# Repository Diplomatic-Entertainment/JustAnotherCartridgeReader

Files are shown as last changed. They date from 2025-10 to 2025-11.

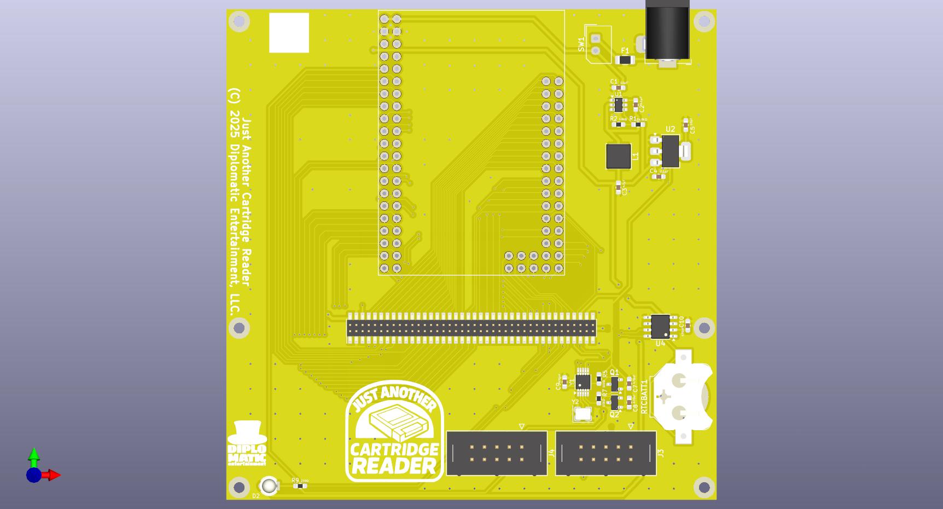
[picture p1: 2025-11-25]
Hardware/JACR_Front.jpg

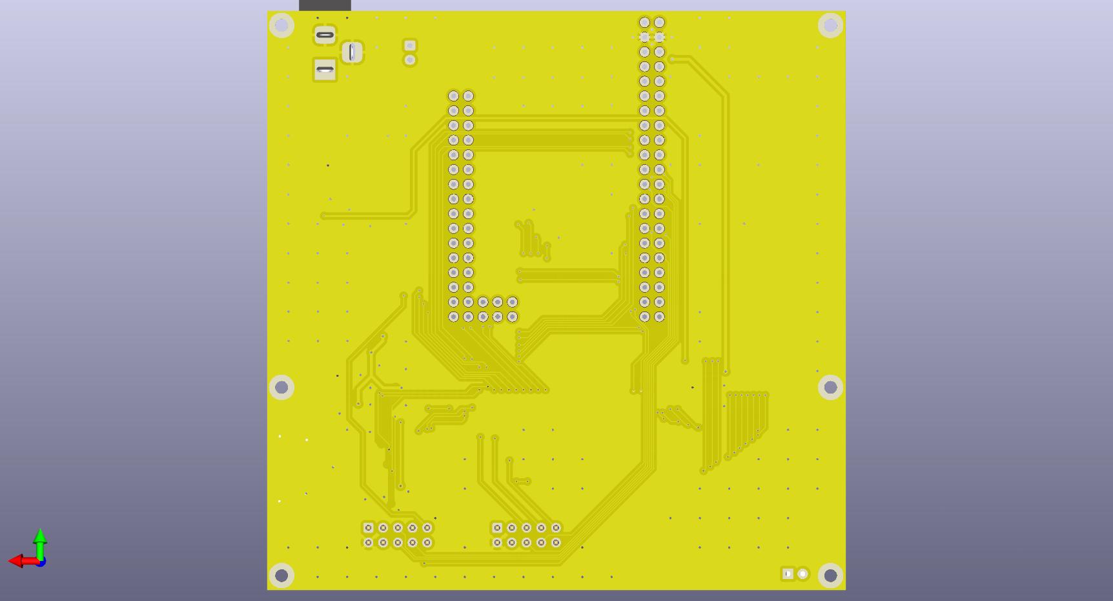
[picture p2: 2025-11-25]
Hardware/JACR_Back.jpg

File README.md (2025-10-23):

# JustAnotherCartridgeReader (JACR)
### An Open Source Cartridge Reader Derivative

JACR uses modified Firmware based on the OSCR Firmware - 
[Original OSCR Project](https://github.com/sanni/cartreader)

## What makes the JACR different from OSCR?
- JACR is designed with a dedicated power circuity allowing both 5V and 3.3V at the same time.  
- JACR uses a different design for adapaters, the pins back to the microcontroller remain the same but the pin pitch is altered and more power pins were added.  
- [JACR Adapters](https://github.com/Diplomatic-Entertainment/JACR-Adapters) are currently designed with logic level converters.   
- **JACR is not directly compatible with OSCR adapers and JACR Adapters are not directly compatible with the OSCR**

## What is the same as the OSCR?
- JACR uses the MEGA2560 microconroller  
- JACR has the RTC and ClockGEN built into the main board  
- Support for all the same Systems as the OSCR  
- JACR complies with Open Source Licensing with source code available for viewing and modifying  

### Open Source Licenses:
Software(everything in Firmware folder) = GPL v3  
Hardware(everything in hardware folder) = CC BY 4.0  
Complies with the original license of the OSCR where applicable

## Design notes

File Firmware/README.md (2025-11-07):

## This Arduino sketch is licensed under the GNU GENERAL PUBLIC LICENSE Version 3 (GPL v3)    

### This means that you are free to:    
- use, modify and distribute this software, even commercially    

### Under the following terms:    
- state changes   
- disclose source   
- same license   

### Limitations:
- Liability   
- Warranty   

More details: https://www.gnu.org/licenses/gpl-3.0.en.html    

## 

Every submodule has it's own setup_XX() function that configures the needed pins and a submenu that lets you choose what you want to do. 
The code directly addresses the pins via the DDR, PIN and PORT registers.   
Please also refer to the [pinout Open Office sheet](https://github.com/sanni/cartreader/blob/master/pinout.ods).    
```
void setup_N64_Controller() {  
  // Output a low signal  
  PORTH &= ~(1 << 4);  
  // Set Controller Data Pin(PH4) to Input  
  DDRH &= ~(1 << 4);  
}  
```

Would be the same as this in a more traditional Arduino sketch:  
```
int dataPin = 7;   

void setup(){    
  // Output a low signal   
  digitalWrite(dataPin, LOW);   
  // Set controller data pin to input  
  pinMode(dataPin, INPUT);  
}  
```
To preserve memory every string is saved into the flash of the Arduino, also called progmem. This is done by using the F() macro.   
```
println_Msg(F("Press Button."));  
```
Also all the menus are stored in progmem and are only recalled to sram when needed.  
```
// N64 controller menu items  
const char N64ContMenuItem1[] PROGMEM = "Test Controller";  
const char N64ContMenuItem2[] PROGMEM = "Read ControllerPak";  
const char N64ContMenuItem3[] PROGMEM = "Write ControllerPak";  
const char* const menuOptionsN64Controller[] PROGMEM = {N64ContMenuItem1, N64ContMenuItem2, N64ContMenuItem3, FSTRING_RESET};
```
In an effort to keep the codebase as portable as possible instead of using the functions supplied by the OLED library directly to print out text, auxiliary functions like `println_Msg` are being used. So if you want to change to another display library you don't need to change all the code but only the helper functions. 
```
void print_Msg(long unsigned int message) {
  if (ENABLE_OLED)
    display.print(message);
  if (ENABLE_SERIAL)
    Serial.print(message);
}
```

For more info please have a look at [this wiki article](https://github.com/sanni/cartreader/wiki/How-to-flash-the-Arduino).   

Needed libraries(already included in the portable Arduino IDE under Releases)   

SD lib: https://github.com/greiman/SdFat    
LCD lib: https://github.com/olikraus/U8g2_Arduino     
Neopixel lib: https://github.com/adafruit/Adafruit_NeoPixel    
Rotary Enc lib: https://github.com/mathertel/RotaryEncoder    
SI5351 lib: https://github.com/etherkit/Si5351Arduino        
RTC lib: https://github.com/adafruit/RTClib (needs BusIO lib: https://github.com/adafruit/Adafruit_BusIO)     
Frequency Counter lib: https://github.com/PaulStoffregen/FreqCount    

### JACR Modifications 
- Renaming directory from cart_reader to firmware forced cart_reader.ino to be renamed firmware.ino
  - Added JACR as hardware refernce where HW5 is also defined
  - Made reference back to OSCR in About
  - Removed 1K Resistor Check in Self Test
  - Removed reset on failure in Self Test
- Modified config.ino
  - JACR is currently based on the HW5 revision
  - Noted to not change HW selection
  - Noted to not enable VSELECT
  - Clock Generator enabled
  - RTC enabled
  - Noted to not enable 3V3FIX (not needed on JACR)
  - Noted to not enable Stability Fix (not need on JACR)
  - Noted to not enable the updated (untested, unlikely to work with intended results) 
  - Enabled SNES Core/CLOCKGEN by default
- Modified oscr.cpp
  - Added JACR suffix to FSTRING_VERSION
  - Changed FSTRING_OSCR from OSCR to JACR
  - Comment out setClockScale VOLTS and CLKSCALE (unused)

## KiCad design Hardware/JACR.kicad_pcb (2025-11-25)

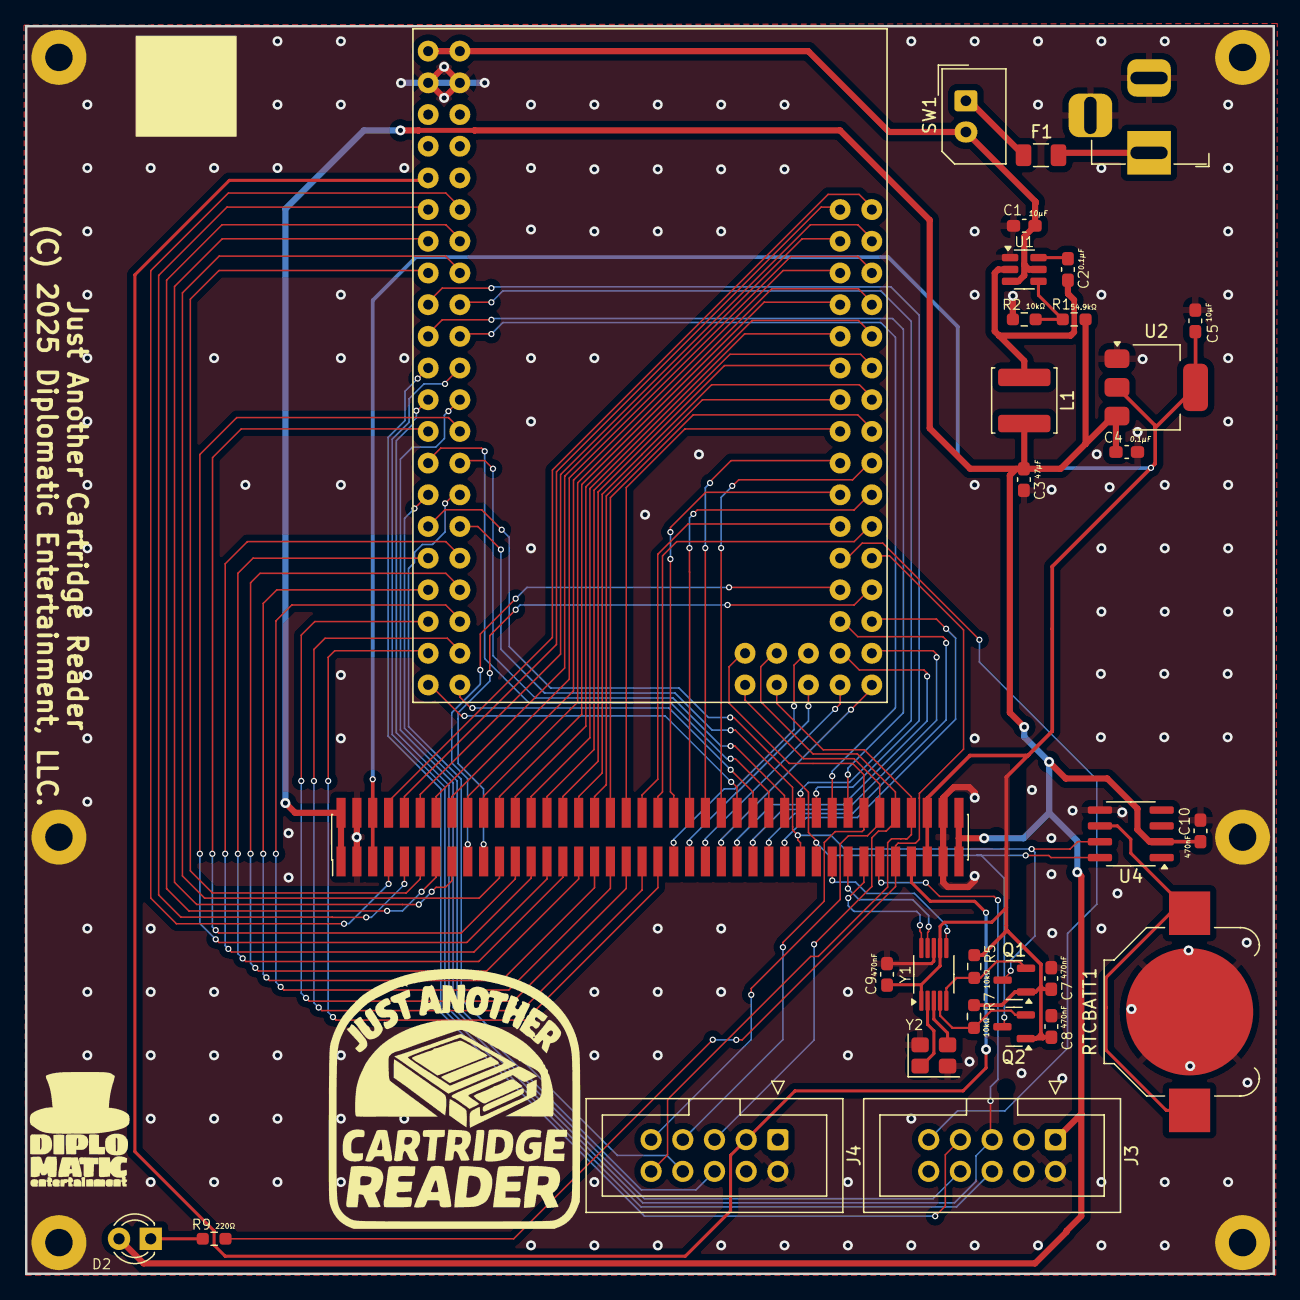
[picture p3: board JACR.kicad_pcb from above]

Board: 2 copper layers, 100.0 x 100.0 mm, 38 parts (0 on the bottom side), 89 nets.

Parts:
BAR**: 2D Barcode 8mm
C1, C5: 10µF; C_0603_1608Metric_Pad1.08x0.95mm_HandSolder
C2, C4: 0.1µF; C_0603_1608Metric_Pad1.08x0.95mm_HandSolder
C3: 47µF; C_0603_1608Metric_Pad1.08x0.95mm_HandSolder
C7, C8, C9, C10: 470nF; C_0603_1608Metric_Pad1.08x0.95mm_HandSolder
D2: LED; LED_D3.0mm_Clear
F1: 1A; Fuse_1206_3216Metric
J1: Barrel_Jack_Switch; BarrelJack_Horizontal
J2: JACR CARTRIDGE SLOT; PinHeader_2x40_P1.27mm_Vertical_SMD
J3: EXP1; IDC-Header_2x05_P2.54mm_Vertical
J4: EXP2; IDC-Header_2x05_P2.54mm_Vertical
L1: 4.7µH; L_APV_ANR5040
M1, M2, M3, M4, M4#2, M4#3: MountingHole_2.2mm_M2_Pad
Q1, Q2: BSS138; SOT-23
R1: 54.9kΩ; R_0603_1608Metric_Pad0.98x0.95mm_HandSolder
R2, R5, R7: 10kΩ; R_0603_1608Metric_Pad0.98x0.95mm_HandSolder
R9: 220Ω; R_0603_1608Metric_Pad0.98x0.95mm_HandSolder
RTCBATT1: Battery_Cell; BatteryHolder_Keystone_3000_1x12mm
SW1: SW_SPST; Molex_SPOX_5267-02A_1x02_P2.50mm_Vertical
U1: TPS562200; SOT-23-6
U2: LD1117S33; SOT-223-3_TabPin2
U4: DS3231MZ; SOIC-8_3.9x4.9mm_P1.27mm
U5: MEGA PRO EMBEDED 2560; MODULE_MEGA_PRO_EMBED_CH340G___ATMEGA2560_SMD
Y1: Si5351A-B-GT; MSOP-10_3x3mm_P0.5mm
Y2: 25Mhz; Crystal_SMD_3225-4Pin_3.2x2.5mm

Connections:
+3V3: C5.1, C7.1, C8.1, C9.1, J2.5 (+3V3), J2.6 (+3V3), J2.75 (+3V3), J2.76 (+3V3), Q1.1 (G), Q2.1 (G), R5.1, R7.1, U2.2 (VO), Y1.1 (VDD), Y1.7 (VDDO)
+5V: C3.1, C4.1, C10.1, D2.2 (A), J2.1 (+5V), J2.2 (+5V), J2.79 (+5V), J2.80 (+5V), J3.1, L1.2, R1.1, U2.3 (VI), U4.2 (VCC)
/SCL: Q2.2 (S), R7.2, Y1.4 (SCL)
/SDA: Q1.2 (S), R5.2, Y1.5 (SDA)
/VBAT: RTCBATT1.1 (+), U4.6 (VBAT)
A0: J2.8 (A0), U5.A0
A1: J2.10 (A1), U5.A1
A2: J2.12 (A2), U5.A2
A3: J2.14 (A3), U5.A3
A4: J2.16 (A4), U5.A4
A5: J2.18 (A5), U5.A5
A6: J2.20 (A6), U5.A6
A7: J2.22 (A7), U5.A7
A8: J2.24 (A8), U5.A8
A9: J2.26 (A9), U5.A9
A10: J2.28 (A10), U5.A10
A11: J2.30 (A11), U5.A11
A12: J2.32 (A12), U5.A12
A13: J2.34 (A13), U5.A13
A14: J2.36 (A14), U5.A14
A15: J2.38 (A15), U5.A15
CLK0: J2.67 (CLK0), Y1.10 (CLK0)
CLK1: J2.65 (CLK1), Y1.9 (CLK1)
CLK2: J2.63 (CLK2), Y1.6 (CLK2)
D0: J2.7 (D0), U5.RX_D0
D1: J2.9 (D1), U5.TX_D1
D2: J2.13 (D2), U5.D2
D3: J2.15 (D3), U5.D3
D4: J2.21 (D4), U5.D4
D5: J2.11 (D5), U5.D5
D6: J2.60 (D6), U5.D6
D7: J2.62 (D7), U5.D7
D8: J2.64 (D8), U5.D8
D9: J2.66 (D9), U5.D9
D10: J3.6, U5.D10
D11: J3.7, U5.D11
D12: J3.8, U5.D12
D13: J2.69 (D13), J3.5, U5.D13
D14: J2.25 (D14), U5.D14
D15: J2.23 (D15), U5.D15
D16: J2.58 (D16), U5.D16
D17: J2.56 (D17), U5.D17
D18: J4.8, U5.D18
D19: J4.6, U5.D19
D20: J2.59 (D20), Q1.3 (D), U4.7 (SDA), U5.D20
D21: J2.61 (D21), Q2.3 (D), U4.8 (SCL), U5.D21
D22: J2.27 (D22), U5.D22
D23: J2.29 (D23), U5.D23
D24: J2.31 (D24), U5.D24
D25: J2.33 (D25), U5.D25
D26: J2.35 (D26), U5.D26
D27: J2.37 (D27), U5.D27
D28: J2.39 (D28), U5.D28
D29: J2.41 (D29), U5.D29
D30: J2.54 (D30), U5.D30
D31: J2.52 (D31), U5.D31
D32: J2.50 (D32), U5.D32
D33: J2.48 (D33), U5.D33
D34: J2.46 (D34), U5.D34
D35: J2.44 (D35), U5.D35
D36: J2.42 (D36), U5.D36
D37: J2.40 (D37), U5.D37
D38: J2.71 (D38), R9.2, U5.D38
D39: J3.9, U5.D39
D40: J2.19 (D40), U5.D40
D41: J2.17 (D41), U5.D41
D42: J2.57 (D42), U5.D42
D43: J2.55 (D43), U5.D43
D44: J2.53 (D44), U5.D44
D45: J2.51 (D45), U5.D45
D46: J2.49 (D46), U5.D46
D47: J2.47 (D47), U5.D47
D48: J2.45 (D48), U5.D48
D49: J2.43 (D49), U5.D49
D50: J2.74 (D50), J4.10, U5.D50
D51: J2.72 (D51), J4.5, U5.D51
D52: J2.70 (D52), J4.9, U5.D52
D53: J2.68 (D53), J4.7, U5.D53
GND: C1.2, C3.2, C4.2, C5.2, C7.2, C8.2, C9.2, C10.2, J1.2, J1.3, J2.3 (GND), J2.4 (GND), J2.77 (GND), J2.78 (GND), J3.2, J4.2, M1.1, M2.1, M3.1, M4.1, M4#2.1, M4#3.1, R2.2, RTCBATT1.2 (-), U1.1 (GND), U2.1 (GND), U4.5 (GND), U5.GND_1, U5.GND_2, Y1.8 (GND), Y2.2, Y2.4
unnamed: D2.1 (K), R9.1
unnamed: F1.1, J1.1
unnamed: F1.2, SW1.1 (A)
unnamed: C2.1, L1.1, U1.2 (SW)
unnamed: C2.2, U1.6 (VBST)
unnamed: R1.2, R2.1, U1.4 (VFB)
unnamed: Y1.2 (XA), Y2.1
unnamed: Y1.3 (XB), Y2.3
RST: J2.73 (RESET), J4.3, U5.RST
VCC: C1.1, SW1.2 (B), U1.3 (VIN), U1.5 (EN), U5.VIN_1, U5.VIN_2

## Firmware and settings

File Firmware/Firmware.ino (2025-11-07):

/**********************************************************************************
                    Cartridge Reader for Arduino Mega2560

   This project represents a community-driven effort to provide
   an easy to build and easy to modify cartridge dumper.

   SD lib: https://github.com/greiman/SdFat
   LCD lib: https://github.com/olikraus/u8g2
   Neopixel lib: https://github.com/adafruit/Adafruit_NeoPixel
   Rotary Enc lib: https://github.com/mathertel/RotaryEncoder
   SI5351 lib: https://github.com/etherkit/Si5351Arduino
   RTC lib: https://github.com/adafruit/RTClib
   Frequency lib: https://github.com/PaulStoffregen/FreqCount

   Thanks to:
   MichlK - ROM Reader for Super Nintendo
   Jeff Saltzman - 4-Way Button
   Wayne and Layne - Video Game Shield menu
   skaman - Cart ROM READER SNES ENHANCED, Famicom Cart Dumper, 2600, 5200, 7800, ARC, ATARI8, BALLY, C64, COLV, FAIRCHILD,
   INTV, LEAP, LJ, LJPRO, MSX, ODY2, PCW, POKEMINI, PV1000, PYUUTA, RCA, TI99, TRS80, VBOY, VECTREX, WSV, VIC20, VSMILE modules
   Tamanegi_taro - PCE and Satellaview modules
   splash5 - GBSmart, Wonderswan, NGP and Super A'can modules
   partlyhuman - Casio Loopy & Atari Lynx module
   hkz & themanbehindthecurtain - N64 flashram commands
   Andrew Brown & Peter Den Hartog - N64 controller protocol
   libdragon - N64 controller checksum functions
   Angus Gratton - CRC32
   Snes9x - SuperFX sram fix
   insidegadgets - GBCartRead
   RobinTheHood - GameboyAdvanceRomDumper
   Gens-gs - Megadrive checksum
   fceux - iNes header
   PsyK0p4T - Sufami Turbo module
   LuigiBlood - SNES Game Processor RAM Cassette module
   herzmx - CPS3 module

   And a special Thank You to all coders and contributors on Github and the Arduino forum:
   Ancyker, Andy-miles, BacteriaMage, Borti4938, Breyell, ButThouMust, CaitSith2, Chomemel, Dakkaron, Ducky92, Fakkuyuu, Gemarcano,
   Hxlnt, InvalidInterrupt, Jiyunomegami, Joshman196, Karimhadjsalem, Kreeblah, Lesserkuma, LuigiBlood, Majorpbx, Mattiacci, Modman,
   Niklasweber, Nsx0r, Partlyhuman, Philenotfound, Pickle, Plaidpants, PsychoFox11, PsyK0p4T, Qufb, RWeick, Ramapcsx2, Sakman55,
   Scrap-a, Sdhizumi, Smesgr9000, Splash5, Tombo89, Uzlopak, Vogelfreiheit, Vpelletier, Wfmarques

   And to nocash for figuring out the secrets of the SFC Nintendo Power cartridge.

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
**********************************************************************************/

#include "OSCR.h"

/******************************************
   Libraries
 *****************************************/

// SD Card
SdFs sd;
FsFile myFile;
#ifdef ENABLE_GLOBAL_LOG
FsFile myLog;
bool dont_log = false;
#endif

// AVR Eeprom
#include <EEPROM.h>
// forward declarations for "T" (for non Arduino IDE)
template<class T> int EEPROM_writeAnything(int ee, const T& value);
template<class T> int EEPROM_readAnything(int ee, T& value);

// Graphic SPI LCD
#ifdef ENABLE_LCD
#include <U8g2lib.h>
U8G2_ST7567_OS12864_F_4W_HW_SPI display(U8G2_R2, /* cs=*/12, /* dc=*/11, /* reset=*/10);
#endif

// Rotary Encoder
#ifdef ENABLE_ROTARY
#include <RotaryEncoder.h>
#define PIN_IN1 18
#define PIN_IN2 19
#ifdef rotate_counter_clockwise
RotaryEncoder encoder(PIN_IN2, PIN_IN1, RotaryEncoder::LatchMode::FOUR3);
#else
RotaryEncoder encoder(PIN_IN1, PIN_IN2, RotaryEncoder::LatchMode::FOUR3);
#endif
int rotaryPos = 0;
#endif

// Choose RGB LED type
#ifdef ENABLE_NEOPIXEL
// Neopixel
#include <Adafruit_NeoPixel.h>
Adafruit_NeoPixel pixels(3, 13, NEO_GRB + NEO_KHZ800);
#endif

typedef enum COLOR_T {
  blue_color,
  red_color,
  purple_color,
  green_color,
  turquoise_color,
  yellow_color,
  white_color,
  black_color,
} color_t;

// Graphic I2C OLED
#ifdef ENABLE_OLED
#include <U8g2lib.h>
U8G2_SSD1306_128X64_NONAME_F_HW_I2C display(U8G2_R0, /* reset=*/U8X8_PIN_NONE);
#endif

// Etherkit Clock Generator
#include <si5351.h>
Si5351 clockgen;
bool i2c_found;

// RTC Library
#ifdef ENABLE_RTC
#define _RTC_H
#include "RTClib.h"
#endif

// Clockgen Calibration
#ifdef OPTION_CLOCKGEN_CALIBRATION
#include "FreqCount.h"
#endif

void _print_FatalError(void) __attribute__((noreturn));
void print_FatalError(const __FlashStringHelper* errorMessage) __attribute__((noreturn));
void print_FatalError(byte errorMessage) __attribute__((noreturn));

/******************************************
  End of inclusions and forward declarations
 *****************************************/

template<class T> int EEPROM_writeAnything(int ee, const T& value) {
  const byte* p = (const byte*)(const void*)&value;
  unsigned int i;
  for (i = 0; i < sizeof(value); i++)
    EEPROM.write(ee++, *p++);
  return i;
}

template<class T> int EEPROM_readAnything(int ee, T& value) {
  byte* p = (byte*)(void*)&value;
  unsigned int i;
  for (i = 0; i < sizeof(value); i++)
    *p++ = EEPROM.read(ee++);
  return i;
}

/******************************************
  Common Strings
 *****************************************/
#define press_button_STR 0
#define sd_error_STR 1
#define reset_STR 2
#define did_not_verify_STR 3
#define _bytes_STR 4
#define error_STR 5
#define create_file_STR 6
#define open_file_STR 7
#define file_too_big_STR 8
#define done_STR 9
#define saving_to_STR 10
#define verifying_STR 11
#define flashing_file_STR 12
#define press_to_change_STR 13
#define right_to_select_STR 14
#define rotate_to_change_STR 15
#define press_to_select_STR 16

// This array holds the most often used strings
constexpr char string_press_button0[] PROGMEM = "Press Button...";
constexpr char string_sd_error1[] PROGMEM = "SD Error";
constexpr char string_did_not_verify3[] PROGMEM = "did not verify";
constexpr char string_bytes4[] PROGMEM = " bytes ";
constexpr char string_error5[] PROGMEM = "Error: ";
constexpr char string_create_file6[] PROGMEM = "Can't create file";
constexpr char string_open_file7[] PROGMEM = "Can't open file";
constexpr char string_file_too_big8[] PROGMEM = "File too big";
constexpr char string_done9[] PROGMEM = "Done";
constexpr char string_saving_to10[] PROGMEM = "Saving to ";
constexpr char string_verifying11[] PROGMEM = "Verifying...";
constexpr char string_flashing_file12[] PROGMEM = "Flashing file ";
constexpr char string_press_to_change13[] PROGMEM = "Press left to Change";
constexpr char string_right_to_select14[] PROGMEM = "and right to Select";
constexpr char string_rotate_to_change15[] PROGMEM = "Rotate to Change";
constexpr char string_press_to_select16[] PROGMEM = "Press to Select";

static constexpr const char* const string_table[] PROGMEM = {
  string_press_button0, string_sd_error1, FSTRING_RESET,
  string_did_not_verify3, string_bytes4, string_error5, string_create_file6,
  string_open_file7, string_file_too_big8, string_done9, string_saving_to10,
  string_verifying11, string_flashing_file12, string_press_to_change13,
  string_right_to_select14, string_rotate_to_change15, string_press_to_select16
};

void print_STR(byte string_number, boolean newline) {
  if (newline)
    println_Msg(FS(pgm_read_word(string_table + string_number)));
  else
    print_Msg(FS(pgm_read_word(string_table + string_number)));
}

/******************************************
  Defines
 *****************************************/

// optimization-safe nop delay
#define NOP __asm__ __volatile__("nop\n\t")

// Button timing
#define debounce 20        // ms debounce period to prevent flickering when pressing or releasing the button
#define DCgap 250          // max ms between clicks for a double click event
#define holdTime 2000      // ms hold period: how long to wait for press+hold event
#define longHoldTime 5000  // ms long hold period: how long to wait for press+hold event

/******************************************
   Variables
 *****************************************/
#ifdef ENABLE_ROTARY
// Button debounce
boolean buttonState = HIGH;          // the current reading from the input pin
boolean lastButtonState = HIGH;      // the previous reading from the input pin
unsigned long lastDebounceTime = 0;  // the last time the output pin was toggled
unsigned long debounceDelay = 50;    // the debounce time; increase if the output flickers
#endif

#ifdef ENABLE_OLED
// Button 1
boolean buttonVal1 = HIGH;           // value read from button
boolean buttonLast1 = HIGH;          // buffered value of the button's previous state
boolean DCwaiting1 = false;          // whether we're waiting for a double click (down)
boolean DConUp1 = false;             // whether to register a double click on next release, or whether to wait and click
boolean singleOK1 = true;            // whether it's OK to do a single click
long downTime1 = -1;                 // time the button was pressed down
long upTime1 = -1;                   // time the button was released
boolean ignoreUp1 = false;           // whether to ignore the button release because the click+hold was triggered
boolean waitForUp1 = false;          // when held, whether to wait for the up event
boolean holdEventPast1 = false;      // whether or not the hold event happened already
boolean longholdEventPast1 = false;  // whether or not the long hold event happened already
// Button 2
boolean buttonVal2 = HIGH;           // value read from button
boolean buttonLast2 = HIGH;          // buffered value of the button's previous state
boolean DCwaiting2 = false;          // whether we're waiting for a double click (down)
boolean DConUp2 = false;             // whether to register a double click on next release, or whether to wait and click
boolean singleOK2 = true;            // whether it's OK to do a single click
long downTime2 = -1;                 // time the button was pressed down
long upTime2 = -1;                   // time the button was released
boolean ignoreUp2 = false;           // whether to ignore the button release because the click+hold was triggered
boolean waitForUp2 = false;          // when held, whether to wait for the up event
boolean holdEventPast2 = false;      // whether or not the hold event happened already
boolean longholdEventPast2 = false;  // whether or not the long hold event happened already
#endif

// Variables for the menu
int choice = 0;
// Temporary array that holds the menu option read out of progmem
char menuOptions[7][20];
boolean ignoreError = 0;

// File browser
#define FILENAME_LENGTH 100
#define FILEPATH_LENGTH 132
#define FILEOPTS_LENGTH 20

char fileName[FILENAME_LENGTH];
char filePath[FILEPATH_LENGTH];
byte currPage;
byte lastPage;
byte numPages;
boolean root = 0;
boolean filebrowse = 0;

// Common
// 21 chars for ROM name, one char for termination
char romName[22];
unsigned long sramSize = 0;
int romType = 0;
byte saveType;
word romSize = 0;
word numBanks = 128;
char checksumStr[9];
bool errorLvl = 0;
byte romVersion = 0;
char cartID[5];
unsigned long cartSize;
unsigned int flashid;
char flashid_str[5];
char vendorID[5];
unsigned long fileSize;
unsigned long sramBase;
unsigned long flashBanks;
bool flashX16Mode;
bool flashSwitchLastBits;

// Variable to count errors
unsigned long writeErrors;

// Operation mode
CORES mode = CORE_MAX;

//remember folder number to create a new folder for every game
int foldern;
// 4 chars for console type, 4 chars for SAVE/ROM, 21 chars for ROM name, 4 chars for folder number, 3 chars for slashes, one char for termination, one char savety
char folder[38];

// Array that holds the data
byte sdBuffer[512];

// soft reset Arduino: jumps to 0
// using the watchdog timer would be more elegant but some Mega2560 bootloaders are buggy with it
void (*resetArduino)(void) __attribute__((noreturn)) = 0;

// Progressbar
void draw_progressbar(uint32_t processedsize, uint32_t totalsize);

// used by MD and NES modules
byte eepbit[8];
byte eeptemp;

// Array to hold iNES header
byte iNES_HEADER[16];
//ID 0-3
//ROM_size 4
//VROM_size 5
//ROM_type 6
//ROM_type2 7
//ROM_type3 8
//Upper_ROM_VROM_size 9
//RAM_size 10
//VRAM_size 11
//TV_system 12
//VS_hardware 13
//reserved 14, 15

//******************************************
// CRC32
//******************************************
// CRC32 lookup table // 256 entries
constexpr uint32_t crc_32_tab[] PROGMEM = { /* CRC polynomial 0xedb88320 */
  0x00000000, 0x77073096, 0xee0e612c, 0x990951ba, 0x076dc419, 0x706af48f,
  0xe963a535, 0x9e6495a3, 0x0edb8832, 0x79dcb8a4, 0xe0d5e91e, 0x97d2d988,
  0x09b64c2b, 0x7eb17cbd, 0xe7b82d07, 0x90bf1d91, 0x1db71064, 0x6ab020f2,
  0xf3b97148, 0x84be41de, 0x1adad47d, 0x6ddde4eb, 0xf4d4b551, 0x83d385c7,
  0x136c9856, 0x646ba8c0, 0xfd62f97a, 0x8a65c9ec, 0x14015c4f, 0x63066cd9,
  0xfa0f3d63, 0x8d080df5, 0x3b6e20c8, 0x4c69105e, 0xd56041e4, 0xa2677172,
  0x3c03e4d1, 0x4b04d447, 0xd20d85fd, 0xa50ab56b, 0x35b5a8fa, 0x42b2986c,
  0xdbbbc9d6, 0xacbcf940, 0x32d86ce3, 0x45df5c75, 0xdcd60dcf, 0xabd13d59,
  0x26d930ac, 0x51de003a, 0xc8d75180, 0xbfd06116, 0x21b4f4b5, 0x56b3c423,
  0xcfba9599, 0xb8bda50f, 0x2802b89e, 0x5f058808, 0xc60cd9b2, 0xb10be924,
  0x2f6f7c87, 0x58684c11, 0xc1611dab, 0xb6662d3d, 0x76dc4190, 0x01db7106,
  0x98d220bc, 0xefd5102a, 0x71b18589, 0x06b6b51f, 0x9fbfe4a5, 0xe8b8d433,
  0x7807c9a2, 0x0f00f934, 0x9609a88e, 0xe10e9818, 0x7f6a0dbb, 0x086d3d2d,
  0x91646c97, 0xe6635c01, 0x6b6b51f4, 0x1c6c6162, 0x856530d8, 0xf262004e,
  0x6c0695ed, 0x1b01a57b, 0x8208f4c1, 0xf50fc457, 0x65b0d9c6, 0x12b7e950,
  0x8bbeb8ea, 0xfcb9887c, 0x62dd1ddf, 0x15da2d49, 0x8cd37cf3, 0xfbd44c65,
  0x4db26158, 0x3ab551ce, 0xa3bc0074, 0xd4bb30e2, 0x4adfa541, 0x3dd895d7,
  0xa4d1c46d, 0xd3d6f4fb, 0x4369e96a, 0x346ed9fc, 0xad678846, 0xda60b8d0,
  0x44042d73, 0x33031de5, 0xaa0a4c5f, 0xdd0d7cc9, 0x5005713c, 0x270241aa,
  0xbe0b1010, 0xc90c2086, 0x5768b525, 0x206f85b3, 0xb966d409, 0xce61e49f,
  0x5edef90e, 0x29d9c998, 0xb0d09822, 0xc7d7a8b4, 0x59b33d17, 0x2eb40d81,
  0xb7bd5c3b, 0xc0ba6cad, 0xedb88320, 0x9abfb3b6, 0x03b6e20c, 0x74b1d29a,
  0xead54739, 0x9dd277af, 0x04db2615, 0x73dc1683, 0xe3630b12, 0x94643b84,
  0x0d6d6a3e, 0x7a6a5aa8, 0xe40ecf0b, 0x9309ff9d, 0x0a00ae27, 0x7d079eb1,
  0xf00f9344, 0x8708a3d2, 0x1e01f268, 0x6906c2fe, 0xf762575d, 0x806567cb,
  0x196c3671, 0x6e6b06e7, 0xfed41b76, 0x89d32be0, 0x10da7a5a, 0x67dd4acc,
  0xf9b9df6f, 0x8ebeeff9, 0x17b7be43, 0x60b08ed5, 0xd6d6a3e8, 0xa1d1937e,
  0x38d8c2c4, 0x4fdff252, 0xd1bb67f1, 0xa6bc5767, 0x3fb506dd, 0x48b2364b,
  0xd80d2bda, 0xaf0a1b4c, 0x36034af6, 0x41047a60, 0xdf60efc3, 0xa867df55,
  0x316e8eef, 0x4669be79, 0xcb61b38c, 0xbc66831a, 0x256fd2a0, 0x5268e236,
  0xcc0c7795, 0xbb0b4703, 0x220216b9, 0x5505262f, 0xc5ba3bbe, 0xb2bd0b28,
  0x2bb45a92, 0x5cb36a04, 0xc2d7ffa7, 0xb5d0cf31, 0x2cd99e8b, 0x5bdeae1d,
  0x9b64c2b0, 0xec63f226, 0x756aa39c, 0x026d930a, 0x9c0906a9, 0xeb0e363f,
  0x72076785, 0x05005713, 0x95bf4a82, 0xe2b87a14, 0x7bb12bae, 0x0cb61b38,
  0x92d28e9b, 0xe5d5be0d, 0x7cdcefb7, 0x0bdbdf21, 0x86d3d2d4, 0xf1d4e242,
  0x68ddb3f8, 0x1fda836e, 0x81be16cd, 0xf6b9265b, 0x6fb077e1, 0x18b74777,
  0x88085ae6, 0xff0f6a70, 0x66063bca, 0x11010b5c, 0x8f659eff, 0xf862ae69,
  0x616bffd3, 0x166ccf45, 0xa00ae278, 0xd70dd2ee, 0x4e048354, 0x3903b3c2,
  0xa7672661, 0xd06016f7, 0x4969474d, 0x3e6e77db, 0xaed16a4a, 0xd9d65adc,
  0x40df0b66, 0x37d83bf0, 0xa9bcae53, 0xdebb9ec5, 0x47b2cf7f, 0x30b5ffe9,
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
};

// Defined as a macros, as compiler disregards inlining requests and these are
// performance-critical functions.
#define UPDATE_CRC(crc, ch) \
  do { \
    uint8_t idx = ((crc) ^ (ch)) & 0xff; \
    uint32_t tab_value = pgm_read_dword(crc_32_tab + idx); \
    (crc) = tab_value ^ ((crc) >> 8); \
  } while (0)

uint32_t updateCRC(const byte* buffer, size_t length, uint32_t crc) {
  for (size_t c = 0; c < length; c++) {
    UPDATE_CRC(crc, buffer[c]);
  }
  return crc;
}

uint32_t calculateCRC(const byte* buffer, size_t length) {
  uint32_t crc = 0xFFFFFFFF;
  crc = updateCRC(buffer, length, crc);
  return ~crc;
}

uint32_t calculateCRC(FsFile& infile) {
  uint32_t byte_count;
  uint32_t crc = 0xFFFFFFFF;

  while ((byte_count = infile.read(sdBuffer, sizeof(sdBuffer))) != 0) {
    crc = updateCRC(sdBuffer, byte_count, crc);
  }
  return ~crc;
}

// Calculate rom's CRC32 from SD
uint32_t calculateCRC(char* fileName, char* folder, unsigned long offset) {
  FsFile infile;
  uint32_t result;

  sd.chdir(folder);
  if (infile.open(fileName, O_READ)) {
    infile.seek(offset);
    result = calculateCRC(infile);
    infile.close();
    return result;
  } else {
    display_Clear();
    print_Msg(F("File "));
    //print_Msg(folder);
    //print_Msg(F("/"));
    //print_Msg(fileName);
    print_FatalError(F(" not found"));
    return 0;
  }
}

/******************************************
   CRC Functions for Atari, Fairchild, Ody2, Arc, etc. modules
 *****************************************/
#if (defined(ENABLE_ODY2) || defined(ENABLE_ARC) || defined(ENABLE_FAIRCHILD) || defined(ENABLE_MSX) || defined(ENABLE_POKE) || defined(ENABLE_2600) || defined(ENABLE_7800) || defined(ENABLE_C64) || defined(ENABLE_VECTREX) || defined(ENABLE_NES) || defined(ENABLE_LYNX) || defined(ENABLE_ATARI8) || defined(ENABLE_BALLY) || defined(ENABLE_LEAP) || defined(ENABLE_LJ) || defined(ENABLE_LJPRO) || defined(ENABLE_PV1000) || defined(ENABLE_PYUUTA) || defined(ENABLE_RCA) || defined(ENABLE_TI99) || defined(ENABLE_TRS80) || defined(ENABLE_VIC20) || defined(ENABLE_VSMILE) || defined(ENABLE_CPS3))

void printCRC(char* checkFile, uint32_t* crcCopy, unsigned long offset) {
  uint32_t crc = calculateCRC(checkFile, folder, offset);
  char tempCRC[9];

  if (crcCopy != NULL) {
    *crcCopy = crc;
  }

  sprintf(tempCRC, "%08lX", crc);
  print_Msg(F("CRC: "));
  println_Msg(tempCRC);
  display_Update();
}
#endif
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
void loop() {
  switch (mode) {
#ifdef ENABLE_N64
    case CORE_N64_CART: return n64CartMenu();
    case CORE_N64_CONTROLLER: return n64ControllerMenu();
#endif
#ifdef ENABLE_SNES
    case CORE_SNES: return snesMenu();
#endif
#if (defined(ENABLE_SFM) && defined(ENABLE_SNES))
    case CORE_SFM: return sfmMenu();
#ifdef ENABLE_FLASH
    case CORE_SFM_FLASH: return sfmFlashMenu();
#endif
    case CORE_SFM_GAME: return sfmGameOptions();
#endif
#ifdef ENABLE_GBX
    case CORE_GB: return gbMenu();
    case CORE_GBA: return gbaMenu();
    case CORE_GBM: return gbmMenu();
#if defined(ENABLE_FLASH)
    case CORE_GB_GBSMART: return gbSmartMenu();
    case CORE_GB_GBSMART_FLASH: return gbSmartFlashMenu();
    case CORE_GB_GBSMART_GAME: return gbSmartGameOptions();
#endif
#endif
#ifdef ENABLE_FLASH8
    case CORE_FLASH8: return flashromMenu8();
#ifdef ENABLE_FLASH16
    case CORE_FLASH16: return flashromMenu16();
    case CORE_EPROM: return epromMenu();
#endif
#endif
#ifdef ENABLE_MD
    case CORE_MD_CART: return mdCartMenu();
    case CORE_SEGA_CD: return segaCDMenu();
#endif
#ifdef ENABLE_PCE
    case CORE_PCE: return pceMenu();
#endif
#if (defined(ENABLE_SV) && defined(ENABLE_SNES))
    case CORE_SV: return svMenu();
#endif
#ifdef ENABLE_NES
    case CORE_NES: return nesMenu();
#endif
#ifdef ENABLE_SMS
    case CORE_SMS: return smsMenu();
#endif
#ifdef ENABLE_WS
    case CORE_WS: return wsMenu();
#endif
#ifdef ENABLE_NGP
    case CORE_NGP: return ngpMenu();
#endif
#ifdef ENABLE_INTV
    case CORE_INTV: return intvMenu();
#endif
#ifdef ENABLE_COLV
    case CORE_COL: return colMenu();
#endif
#ifdef ENABLE_VBOY
    case CORE_VBOY: return vboyMenu();
#endif
#ifdef ENABLE_WSV
    case CORE_WSV: return wsvMenu();
#endif
#ifdef ENABLE_PCW
    case CORE_PCW: return pcwMenu();
#endif
#ifdef ENABLE_ODY2
    case CORE_ODY2: return ody2Menu();
#endif
#ifdef ENABLE_ARC
    case CORE_ARC: return arcMenu();
#endif
#ifdef ENABLE_FAIRCHILD
    case CORE_FAIRCHILD: return fairchildMenu();
#endif
#ifdef ENABLE_SUPRACAN
    case CORE_SUPRACAN: return suprAcanMenu();
#endif
#ifdef ENABLE_MSX
    case CORE_MSX: return msxMenu();
#endif
#ifdef ENABLE_POKE
    case CORE_POKE: return pokeMenu();
#endif
#ifdef ENABLE_LOOPY
    case CORE_LOOPY: return loopyMenu();
#endif
#ifdef ENABLE_C64
    case CORE_C64: return c64Menu();
#endif
#ifdef ENABLE_2600
    case CORE_2600: return a2600Menu();
#endif
#ifdef ENABLE_5200
    case CORE_5200: return a5200Menu();
#endif
#ifdef ENABLE_7800
    case CORE_7800: return a7800Menu();
#endif
#ifdef ENABLE_LYNX
    case CORE_LYNX: return lynxMenu();
#endif
#ifdef ENABLE_VECTREX
    case CORE_VECTREX: return vectrexMenu();
#endif
#ifdef ENABLE_JAGUAR
    case CORE_JAGUAR: return jagMenu();
#endif
#if (defined(ENABLE_ST) && defined(ENABLE_SNES))
    case CORE_ST: return stMenu();
#endif
#if (defined(ENABLE_GPC) && defined(ENABLE_SNES))
    case CORE_GPC: return gpcMenu();
#endif
#ifdef ENABLE_ATARI8
    case CORE_ATARI8: return atari8Menu();
#endif
#ifdef ENABLE_BALLY
    case CORE_BALLY: return ballyMenu();
#endif
#ifdef ENABLE_LJ
    case CORE_LJ: return ljMenu();
#endif
#ifdef ENABLE_LJPRO
    case CORE_LJPRO: return ljproMenu();
#endif
#ifdef ENABLE_PV1000
    case CORE_PV1000: return pv1000Menu();
#endif
#ifdef ENABLE_VIC20
    case CORE_VIC20: return vic20Menu();
#endif
#ifdef ENABLE_LEAP
    case CORE_LEAP: return leapMenu();
#endif
#ifdef ENABLE_RCA
    case CORE_RCA: return rcaMenu();
#endif
#ifdef ENABLE_TI99
    case CORE_TI99: return ti99Menu();
#endif
#ifdef ENABLE_PYUUTA
    case CORE_PYUUTA: return pyuutaMenu();
#endif
#ifdef ENABLE_TRS80
    case CORE_TRS80: return trs80Menu();
#endif
#ifdef ENABLE_VSMILE
    case CORE_VSMILE: return vsmileMenu();
#endif
#if (defined(ENABLE_CPS3) && defined(ENABLE_FLASH8) && defined(ENABLE_FLASH16))
    case CORE_CPS3_CART: return flashromCPS_Cartridge();
    case CORE_CPS3_128SIMM: return flashromCPS_SIMM2x8();
    case CORE_CPS3_64SIMM: return flashromCPS_SIMM4x8();
#endif
    case CORE_MAX: return resetArduino();
  }
}

//******************************************
// End of File
//******************************************

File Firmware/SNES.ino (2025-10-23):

//******************************************
// SUPER NINTENDO MODULE
//******************************************
#ifdef ENABLE_SNES

/******************************************
  Defines
 *****************************************/
// SNES Hi and LoRom, SA is HI with different Sram dumping
#define EX 4
#define SA 3
#define HI 1
#define LO 0

/******************************************
   Variables
 *****************************************/
// Define SNES Cart Reader Variables
int romSpeed = 0;  // 0 = SlowROM, 3 = FastROM
int romChips = 0;  // 0 = ROM only, 1 = ROM & RAM, 2 = ROM & Save RAM,  3 = ROM & DSP1, 4 = ROM & RAM & DSP1, 5 = ROM & Save RAM & DSP1, 19 = ROM & SFX
// 227 = ROM & RAM & GameBoy data, 243 = CX4, 246 = ROM & DSP2
byte romSizeExp = 0;  // ROM-Size Exponent
boolean NP = false;
byte cx4Type = 0;
byte cx4Map = 0;

/******************************************
  Menu
*****************************************/
// SNES/Nintendo Power SF Memory start menu
static const char snsMenuItem1[] PROGMEM = "SNES/SFC cartridge";
static const char snsMenuItem2[] PROGMEM = "SF Memory Cassette";
static const char snsMenuItem3[] PROGMEM = "Satellaview BS-X";
static const char snsMenuItem4[] PROGMEM = "Sufami Turbo";
static const char snsMenuItem5[] PROGMEM = "Game Processor RAM";
static const char snsMenuItem6[] PROGMEM = "Flash repro";
#ifdef OPTION_CLOCKGEN_CALIBRATION
static const char snsMenuItem7[] PROGMEM = "Calibrate Clock";
static const char* const menuOptionsSNS[] PROGMEM = { snsMenuItem1, snsMenuItem2, snsMenuItem3, snsMenuItem4, snsMenuItem5, snsMenuItem6, snsMenuItem7 };
#else
static const char* const menuOptionsSNS[] PROGMEM = { snsMenuItem1, snsMenuItem2, snsMenuItem3, snsMenuItem4, snsMenuItem5, snsMenuItem6, FSTRING_RESET };
#endif

// SNES menu items
static const char SnesMenuItem4[] PROGMEM = "Test SRAM";
static const char SnesMenuItem6[] PROGMEM = "Force cart type";
static const char* const menuOptionsSNES[] PROGMEM = { FSTRING_READ_ROM, FSTRING_READ_SAVE, FSTRING_WRITE_SAVE, SnesMenuItem4, FSTRING_REFRESH_CART, SnesMenuItem6, FSTRING_RESET };

// Manual config menu items
static const char confMenuItem1[] PROGMEM = "Use header info";
static const char confMenuItem2[] PROGMEM = "4MB LoROM 256K SRAM";
static const char confMenuItem3[] PROGMEM = "4MB HiROM 64K SRAM";
static const char confMenuItem4[] PROGMEM = "6MB ExROM 256K SRAM";
static const char* const menuOptionsConfManual[] PROGMEM = { confMenuItem1, confMenuItem2, confMenuItem3, confMenuItem4, FSTRING_RESET };

#if (defined(ENABLE_FLASH) && defined(ENABLE_FLASH8))
// Repro menu items
static const char reproMenuItem1[] PROGMEM = "CFI LoROM";
static const char reproMenuItem2[] PROGMEM = "CFI HiROM";
static const char reproMenuItem3[] PROGMEM = "LoROM (P0)";
static const char reproMenuItem4[] PROGMEM = "HiROM (P0)";
static const char reproMenuItem5[] PROGMEM = "ExLoROM (P1)";
static const char reproMenuItem6[] PROGMEM = "ExHiROM (P1)";
static const char* const menuOptionsRepro[] PROGMEM = { reproMenuItem1, reproMenuItem2, reproMenuItem3, reproMenuItem4, reproMenuItem5, reproMenuItem6, FSTRING_RESET };

// CFI ROM config
static const char reproCFIItem1[] PROGMEM = "1x 2MB";
static const char reproCFIItem2[] PROGMEM = "2x 2MB";
static const char reproCFIItem3[] PROGMEM = "1x 4MB";
static const char reproCFIItem4[] PROGMEM = "2x 4MB";
static const char reproCFIItem5[] PROGMEM = "4x 2MB";
static const char reproCFIItem6[] PROGMEM = "1x 8MB";
static const char* const menuOptionsReproCFI[] PROGMEM = { reproCFIItem1, reproCFIItem2, reproCFIItem3, reproCFIItem4, reproCFIItem5, reproCFIItem6, FSTRING_RESET };

/* ROM file order
  static const char reproEXItem1[] PROGMEM = "ExROM (CDAB)";
  static const char reproEXItem2[] PROGMEM = "standard (ABCD)";
  static const char* const menuOptionsReproEX[] PROGMEM = { reproEXItem1, reproEXItem2, FSTRING_RESET };
*/

/*boolean reproEXMenu() {
  boolean fileOrder = 0;
  // create menu with title and 3 options to choose from
  unsigned char snsReproEX;
  // Copy menuOptions out of progmem
  convertPgm(menuOptionsReproEX, 3);
  snsReproEX = question_box(F("ROM file order"), menuOptions, 3, 0);

  // wait for user choice to come back from the question box menu
  switch (snsReproEX) {
    case 0:
      fileOrder = 1;
      break;
    case 1:
      fileOrder = 0;
      break;
    case 2:
      resetArduino();
      break;
  }
  return fileOrder;
  }*/

// Setup number of flashroms
void reproCFIMenu() {
  boolean reversed = 1;
  // create menu with title and 7 options to choose from
  unsigned char snsReproCFI;
  // Copy menuOptions out of progmem
  convertPgm(menuOptionsReproCFI, 7);
  snsReproCFI = question_box(F("Select Flash Config"), menuOptions, 7, 0);

  // wait for user choice to come back from the question box menu
  switch (snsReproCFI) {
    case 0:
      setupCFI();
      flashSize = 2097152;
      writeCFI_Flash(1, 1, 0);
      verifyFlash(1, 1, 0);
      break;

    case 1:
      setupCFI();
      flashSize = 4194304;
      // Write first rom chip
      writeCFI_Flash(1, 2, 0);
      verifyFlash(1, 2, 0);
      delay(300);

      // Switch to second ROM chip, see flash.ino low level functions line 811
      // LoROM
      if (mapping == 1)
        mapping = 122;
      // HiROM
      else if (mapping == 2)
        mapping = 222;

      // Write second rom chip
      display_Clear();
      writeCFI_Flash(2, 2, 0);
      verifyFlash(2, 2, 0);
      break;

    case 2:
      setupCFI();
      flashSize = 4194304;
      writeCFI_Flash(1, 1, 0);
      verifyFlash(1, 1, 0);
      break;

    case 3:
      //reversed = reproEXMenu();
      setupCFI();
      flashSize = 8388608;
      // Write first rom chip
      writeCFI_Flash(1, 2, reversed);
      verifyFlash(1, 2, reversed);
      delay(300);

      // Switch to second ROM chip, see flash.ino low level functions line 811
      // LoROM
      if (mapping == 1)
        mapping = 124;
      // HiROM
      else if (mapping == 2)
        mapping = 224;

      // Write second rom chip
      display_Clear();
      writeCFI_Flash(2, 2, reversed);
      verifyFlash(2, 2, reversed);
      break;

    case 4:
      //reversed = reproEXMenu();
      setupCFI();
      flashSize = 8388608;
      // Write first rom chip
      writeCFI_Flash(1, 4, reversed);
      verifyFlash(1, 4, reversed);
      delay(300);

      // Switch to second ROM chip, see flash.ino low level functions line 811
      // LoROM
      if (mapping == 1)
        mapping = 122;
      // HiROM
      else if (mapping == 2)
        mapping = 222;

      // Write second rom chip
      display_Clear();
      writeCFI_Flash(2, 4, reversed);
      verifyFlash(2, 4, reversed);

      // Switch to third ROM chip
      // LoROM
      if (mapping == 122)
        mapping = 124;
      // HiROM
      else if (mapping == 222)
        mapping = 224;
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

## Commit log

2025-10-23 commiting all current modification
    [JACR.kicad_pcb, JACR.kicad_sch]
2025-11-02 Wrong Resistor values for the power regulator circuit
    Not sure where I got the old values but rereading the data sheet and testing is key to not overvolt anything
    [JACR.kicad_pcb, JACR.kicad_sch]
2025-11-06 Reroute traces going to the display connectors
    Added logos as well
    [JACR.kicad_pcb]
2025-11-07 Modified power circuitry
    Changed inductor to a more readily available part
    Simplified 3.3V rail to linear regulator part
    After some testing, reduced fuse value, the whole unit barely hits 1 amp, might be higher during dumping
    [JACR.kicad_pcb, JACR.kicad_sch]
2025-11-07 Fixing references
    Undoing some prior changes while working thru debugging and updated references to OSCR to JACR
    [Firmware.ino]
2025-11-07 Self Test changes
    Removed 1K Resistor test (Only Applicable to the N64 Controller)
    Removed rest on failure in Self Test
    [Firmware.ino]
2025-11-08 Widen 3.3V rail traces
    [JACR.kicad_pcb]
2025-11-10 Modified Clock Gnerator/RTC Circuit
    I believe putting the RTC I2C lines behind the transistors and pullups is causing problems with it not registering as present all the time. It may also be interfering with the Clock Generator.
    [JACR.kicad_pcb, JACR.kicad_sch]
2025-11-10 Changing the Mega2560 footprint back to through-hole
    Making it SMD seems to have provided no benefits and may have actually caused issues regarding data transfer.
    Currently no successful dump of any cartridge has occurred.
    [JACR.kicad_pcb]
2025-11-10 Updated board images
    [JACR.kicad_pcb]
2025-11-25 Corrected Source and Drain inputs on BSS138 in clock generator circuit
    It would seem I have the 3V and 5V flipped and may have been the cause of my clock generator appearing to not work
    also made adjustments to some traces
    [JACR.kicad_pcb, JACR.kicad_sch]

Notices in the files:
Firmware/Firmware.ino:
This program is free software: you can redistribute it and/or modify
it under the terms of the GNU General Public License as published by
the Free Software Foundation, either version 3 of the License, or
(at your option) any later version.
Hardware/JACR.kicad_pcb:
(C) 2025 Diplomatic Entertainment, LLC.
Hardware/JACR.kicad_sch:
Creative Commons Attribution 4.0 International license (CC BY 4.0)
